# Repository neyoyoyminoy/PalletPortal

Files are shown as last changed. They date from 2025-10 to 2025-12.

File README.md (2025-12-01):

# palletPortal

Pallet Portal is a dual archway automated pallet scanning system designed to streamline outbound shipping operations by integrating barcode detection, object tracking, and manifest verification. It uses the **NVIDIA Jetson Orin Nano**, custom 3D printed hardware, and a Python graphical user interface.

## Overview
- Dual IMX219 cameras for live barcode capture and object tracking.  
- Integrated IR barcode scanner for redundancy and precision.  
- Ultrasonic ping sensors for pallet presence detection and GUI activation.  
- Custom PyQt GUI for real time feedback, mode selection, and system status.  
- Fully 3D printed button interface and display housing, mounted on a dual arch frame.

## Features
- Live dual camera video feed via GStreamer pipeline.  
- Barcode detection and comparison using Pillow/pyzbar/ZXing.  
- Ultrasonic sensor input synchronized with GUI states to prevent crosstalk.  
- Automatic USB manifest detection and reading.  
- Hardware input mapped to GUI navigation (down, cancel, select, up).  
- Custom layered button icons designed in Fusion for tactile control.  

## Hardware
- Jetson Orin Nano Developer Kit  
- Dual IMX219 Cameras  
- Ultrasonic Ping Sensors (HC-SR04)  
- IR Barcode Scanner  
- 3D Printed Components: Display enclosure, button case, dual layer buttons, scaled pallet model (203 mm width)

## Software Stack
| Component | Description |
|---|---|
| Python 3 | Main control and GUI logic |
| PyQt5/Pillow | GUI display and image processing |
| GStreamer | Real time camera pipeline |
| pyzbar/ZXing | Barcode decoding (OpenCV free alternatives) |
| GPIO/Jetson.GPIO | Peripheral communication |
| Threading | Dual camera and sensor concurrency management |

## Current Focus
- Refining UI housing and crossmember mounting.  
- Fusing YOLO individuality to Pillow supportive lightweight detection.  
- Optimizing IR scanner and camera coordination to prevent redundant reads.  
- Improving print efficiency for long 3D jobs (>10 hours per iteration).  

## Known Issues
- Occasional PyQt layout and event conflicts.  
- Camera sensor ID mismatches between CAM0 and CAM1.  
- nvargus daemon instability under high load capture.  
- Jetson thermal throttling during extended use.  
- 3D print size limitations requiring segmented builds.  

## Setup Instructions
```bash
git clone https://github.com/neyoyoyminoy/PalletPortal.git
cd PalletPortal

sudo apt install python3-pyqt5 gstreamer1.0-tools
pip install pillow pyzbar jetson-gpio

python3 GUIv12.py

#this is an optional single camera test; make sure to see current header pin configuration; there can only be sensor 1 and 2 from the 22 header pins
gst-launch-1.0 nvarguscamerasrc sensor-id=0 ! 'video/x-raw(memory:NVMM),width=1280,height=720,framerate=30/1' ! nvvidconv ! videoconvert ! xvimagesink
```

## Contributors
- **Brendan Nellis** — Lead Developer, Hardware Integration, GUI and System Design
- **Simeon-Paul O'James** — Lead AI Model Developer
- **Jose Escareno II** — Lead Hardware Engineer
- **Elliot Cid** — Power Engineer
- **Jim Yanney** — Hardware and Software Implementation Engineer

## License
This project is for academic and research purposes under UTSA Senior Design Fall 2025.  
All code and designs are open for non-commercial educational use.

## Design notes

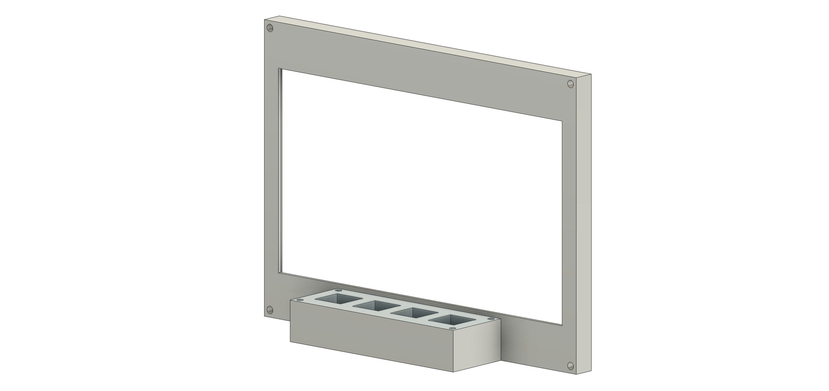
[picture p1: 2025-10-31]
uiCasing/UIv1.png

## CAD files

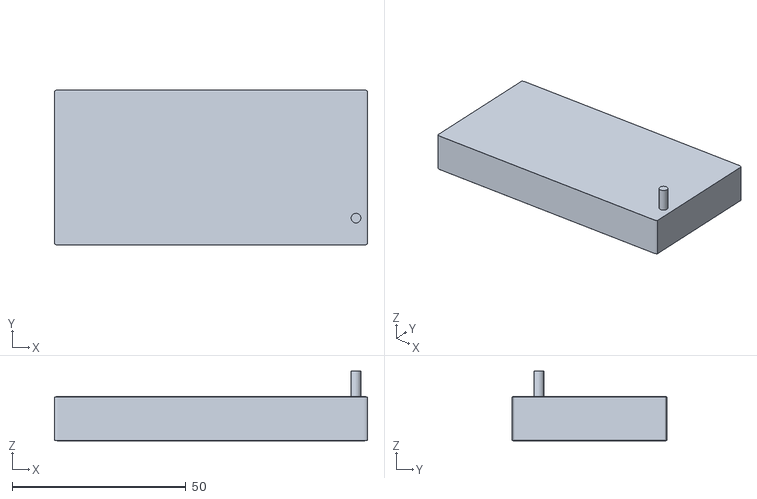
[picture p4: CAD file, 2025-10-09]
3Dprinting/buttonCase/buttonCaseTop.stl
90.0 x 44.7 x 20.0

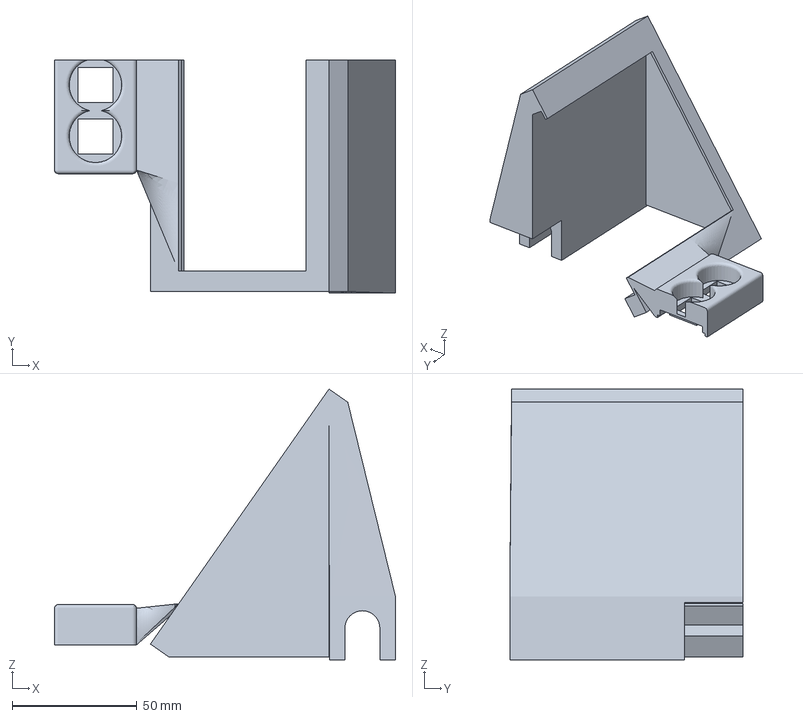
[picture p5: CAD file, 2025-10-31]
uiCasing/UIv2part3.3mf
136.5 x 93.4 x 108.4 mm

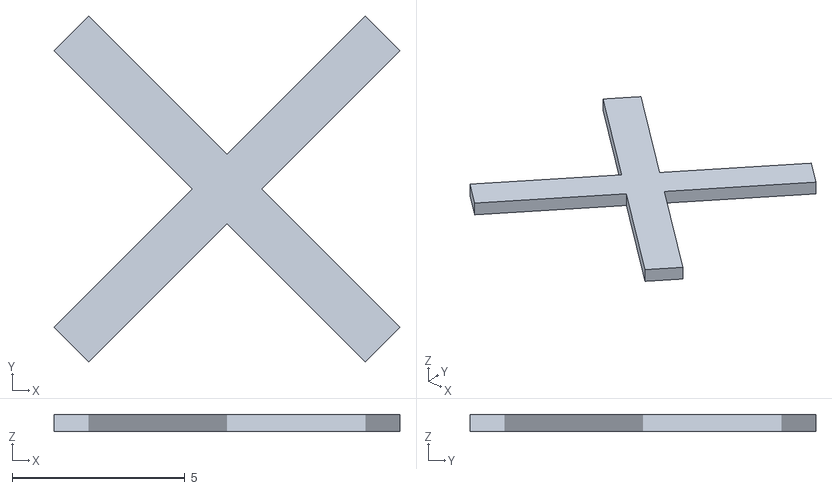
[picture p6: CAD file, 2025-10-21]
3Dprinting/xIcon.stl
10.0 x 10.0 x 0.5

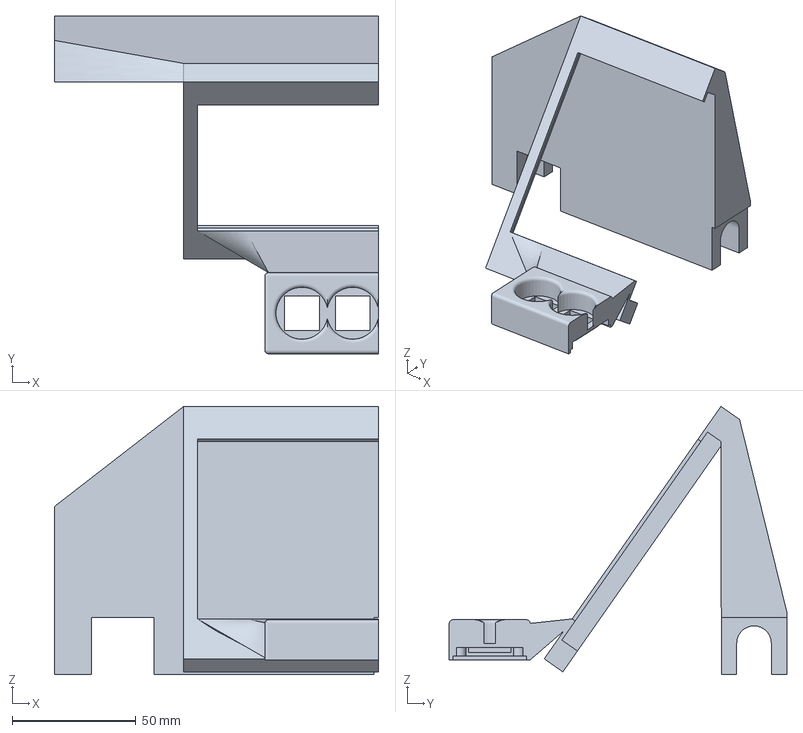
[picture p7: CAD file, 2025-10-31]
uiCasing/UIv2part2.3mf
131.0 x 136.5 x 108.4 mm

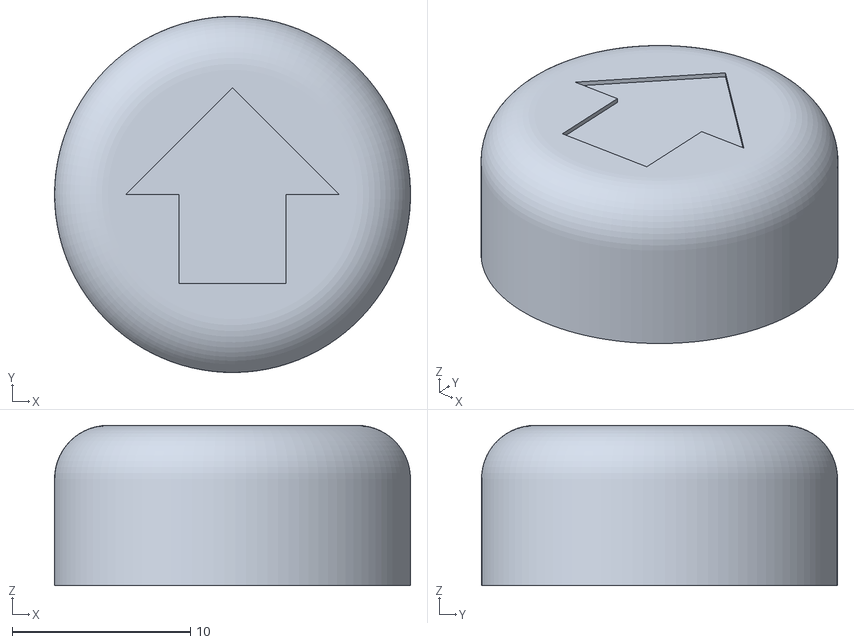
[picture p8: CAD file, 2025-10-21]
3Dprinting/upButtonCap.stl
20.0 x 20.0 x 9.00

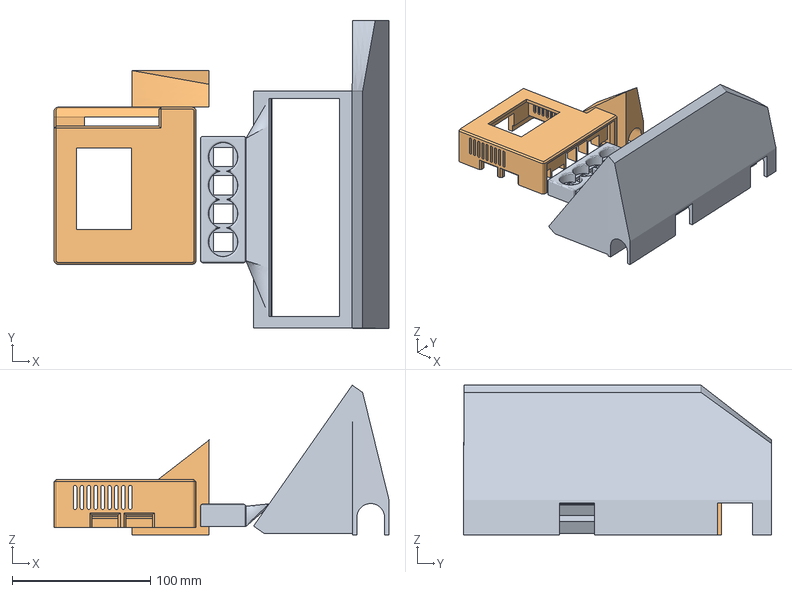
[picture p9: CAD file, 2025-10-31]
uiCasing/UIv3.3mf
242.7 x 223.5 x 108.4 mm
UIv3.stl_A
UIv3.stl_B

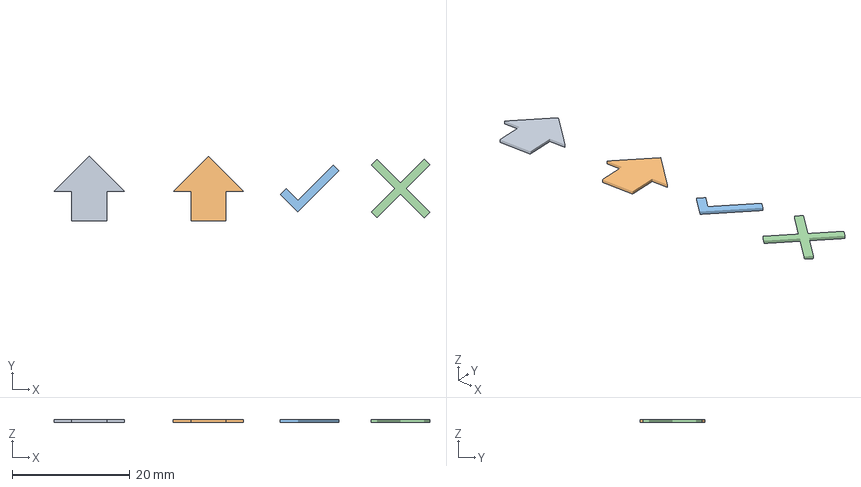
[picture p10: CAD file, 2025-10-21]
3Dprinting/arrowIcon.3mf
64.0 x 11.0 x 0.5 mm
arrowIcon.stl x 2
selIcon.stl
xIcon.stl

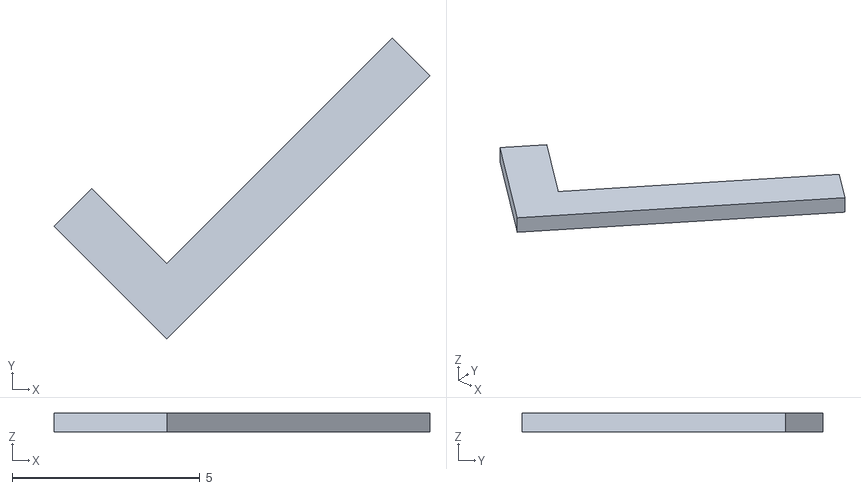
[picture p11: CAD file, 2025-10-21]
3Dprinting/selIcon.stl
10.0 x 8.00 x 0.5

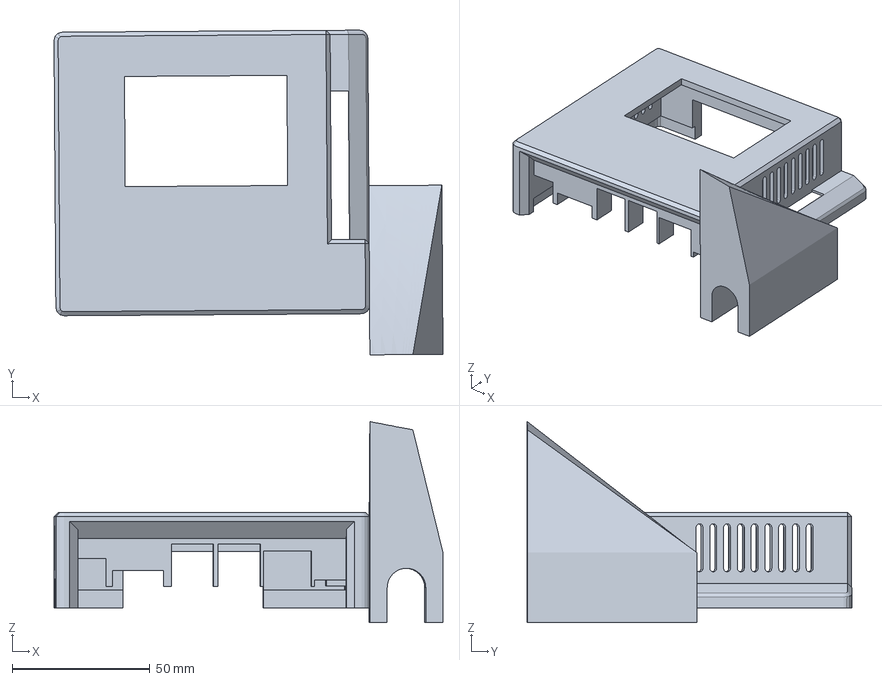
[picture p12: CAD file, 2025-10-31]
uiCasing/UIv2JetsonCasing.3mf
141.3 x 117.9 x 73.0 mm

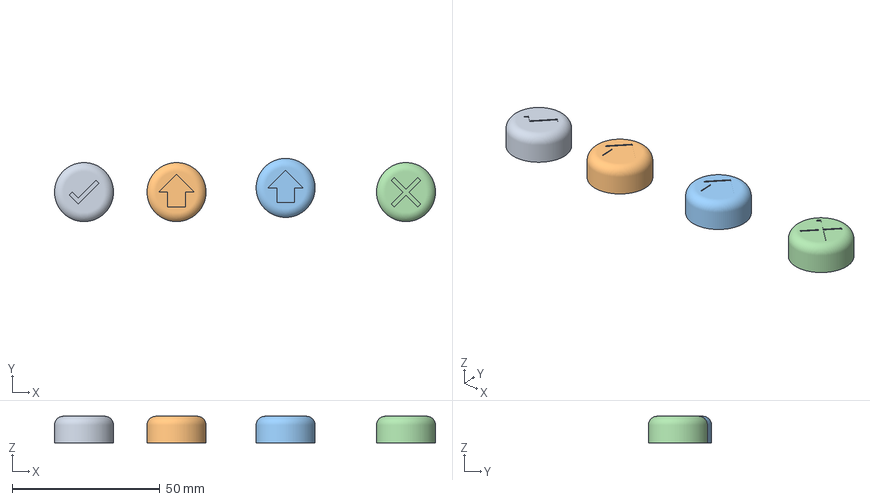
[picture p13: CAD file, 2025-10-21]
3Dprinting/selButtonCap.3mf
129.1 x 21.4 x 9.00 mm
selButtonCap.stl
upButtonCap.stl x 2
xbuttonCap.stl

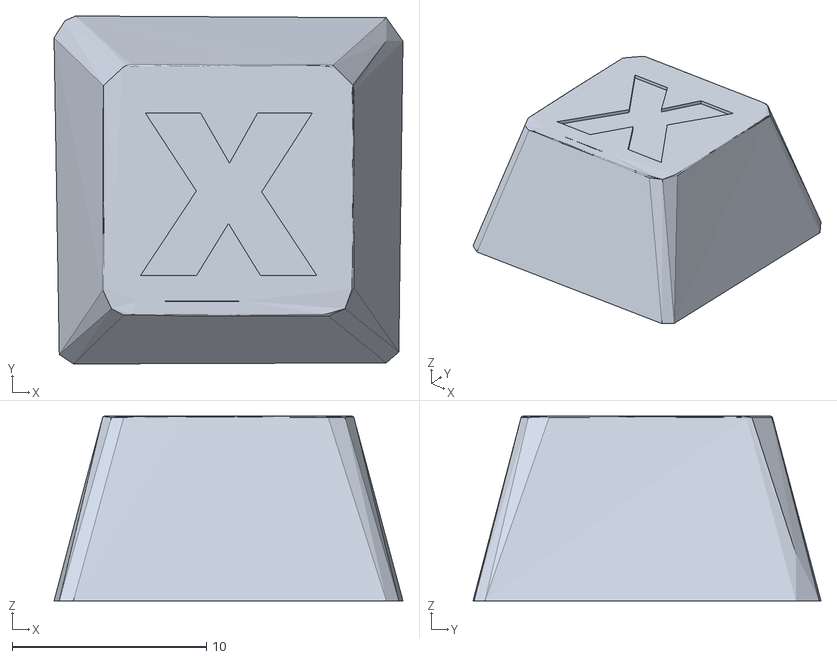
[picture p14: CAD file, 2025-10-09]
3Dprinting/xKey.stl
18.0 x 17.9 x 9.50

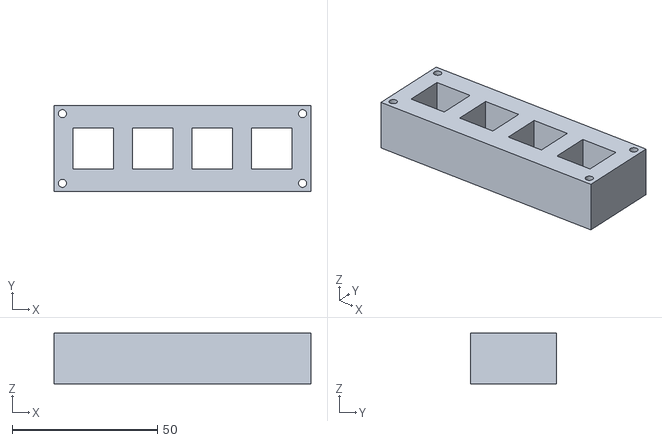
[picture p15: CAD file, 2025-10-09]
3Dprinting/buttonHousingv1.stl
88.6 x 29.8 x 17.5

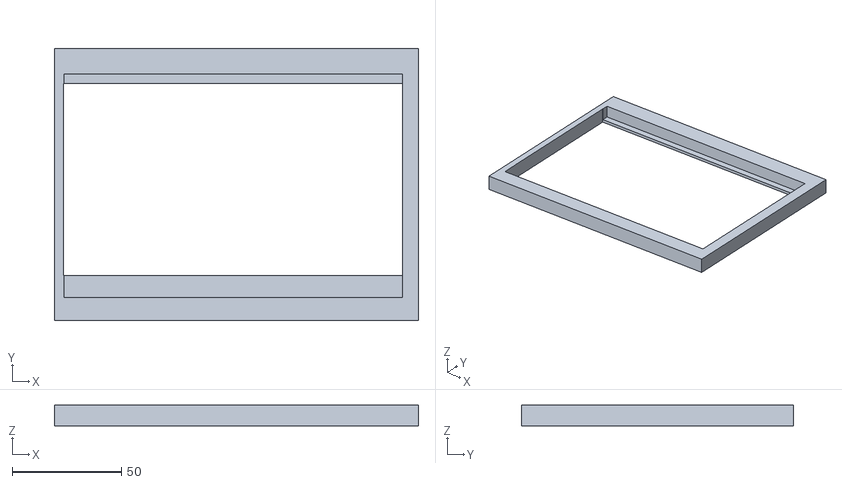
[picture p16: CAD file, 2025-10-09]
3Dprinting/displayCasev3.stl
166.5 x 124.6 x 9.40

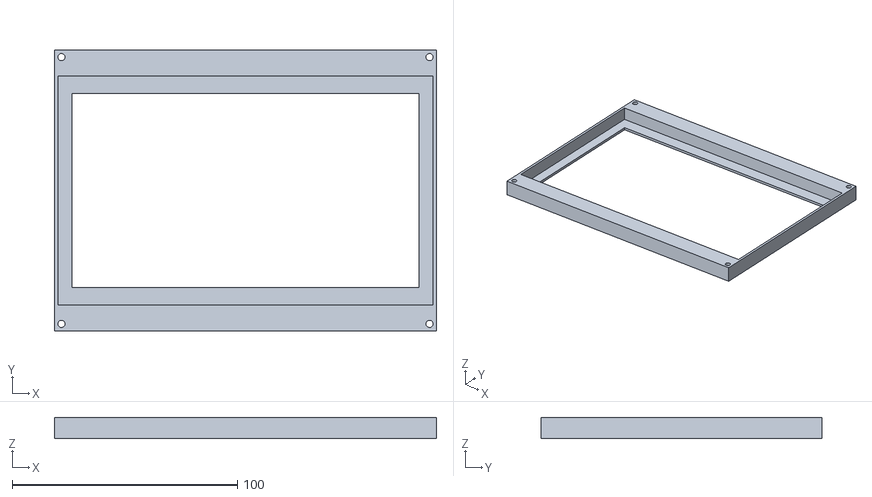
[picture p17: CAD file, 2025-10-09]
3Dprinting/displayCasev2.stl
169.5 x 124.6 x 9.40

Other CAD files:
3Dprinting/buttonCapv3.stl
uiCasing/UIv2.3mf
3Dprinting/xbuttonCap.stl
3Dprinting/selKey.stl
3Dprinting/arrowIcon.stl
3Dprinting/buttonCapv2.stl
3Dprinting/buttonCapv4.stl
3Dprinting/buttonCapv5.stl
3Dprinting/buttonHousingv2.stl
3Dprinting/selButtonCap.stl
uiCasing/UIv2.stl
uiCasing/UIv3.f3z
uiCasing/UIv3.stl

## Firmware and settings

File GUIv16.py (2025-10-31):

'''
this version is built on v15 to implement the Pillow barcode detection and pyzbar decoding from Simeon's code(s)
'''

import os
import re
import sys
import time
from pathlib import Path
from dataclasses import dataclass
from typing import List, Optional, Tuple

from PyQt5.QtCore import Qt, QTimer, pyqtSignal, QObject, QThread
from PyQt5.QtGui import QFont
from PyQt5.QtWidgets import (
    QApplication, QWidget, QLabel, QVBoxLayout, QStackedWidget, QTextEdit
)

#---GPIO for the Jetson Orin Nano---
try:
    import Jetson.GPIO as GPIO #from nvidia jetson gpio docs
    GPIO_AVAILABLE = True
except Exception:
    GPIO_AVAILABLE = False

BARCODE_FILENAME_CANDIDATES = ["barcodes.txt"] #this looks for the manifest text file on the flashdrive
REQUIRED_COUNT = 10 #this was just for testing count detection
REQUIRED_LENGTH = 10 #helps avoid auto reads that arent real barcodes

def guess_mount_roots():
    roots = set()
    user = os.environ.get("USER") or os.environ.get("LOGNAME") or ""
    for base in ["/media", "/mnt", "/run/media"]:
        roots.add(base)
        if user:
            roots.add(os.path.join(base, user))
    roots.add("/media/jetson")
    try:
        with open("/proc/mounts", "r", encoding="utf-8", errors="ignore") as f:
            for line in f:
                parts = line.split()
                if len(parts) >= 3:
                    mnt = parts[1]
                    fstype = parts[2].lower()
                    if any(fs in fstype for fs in ("vfat", "exfat", "ntfs", "fuseblk")):
                        roots.add(mnt)
    except Exception:
        pass
    return [r for r in sorted(roots) if os.path.exists(r)]

DEFAULT_MOUNT_ROOTS = guess_mount_roots() #this gets the possible usb mount points

@dataclass
class ShipmentList:
    def __init__(self, barcodes):
        self.barcodes = barcodes

    @staticmethod
    def parse(text: str):
        if text and text[0] == "\ufeff":
            text = text[1:]

        tokens = re.findall(r"(?<!\d)\d{10}(?!\d)", text) #based on stackoverflow regex for grabbing 10-digit barcodes

        seen = set()
        unique_tokens = []
        for t in tokens:
            if t not in seen:
                seen.add(t)
                unique_tokens.append(t)

        return ShipmentList(unique_tokens) if len(unique_tokens) == 10 else None


class USBWatcher(QObject):
    validListFound = pyqtSignal(ShipmentList, str)
    status = pyqtSignal(str)

    def __init__(self, mount_roots=None, filename_candidates=None, poll_ms=1000, parent=None):
        super().__init__(parent)
        self.mount_roots = mount_roots or DEFAULT_MOUNT_ROOTS
        self.filename_candidates = [c.lower() for c in (filename_candidates or BARCODE_FILENAME_CANDIDATES)] #this looks for the manifest text file on the flashdrive
        self.timer = QTimer(self)
        self.timer.setInterval(poll_ms)
        self.timer.timeout.connect(self.scan_once)

    def start(self):
        self.scan_once()
        self.timer.start()

    def stop(self):
        self.timer.stop()

    def scan_once(self):
        for root in self.mount_roots:
            if not os.path.exists(root):
                continue
            for dirpath, dirnames, filenames in os.walk(root):
                depth = dirpath.strip(os.sep).count(os.sep) - root.strip(os.sep).count(os.sep)
                if depth > 2:
                    dirnames[:] = []
                    continue
                if any(p in dirpath for p in ("/proc", "/sys", "/dev", "/run/lock")):
                    continue
                lower_files = {fn.lower(): fn for fn in filenames}
                for cand_lower in self.filename_candidates:
                    if cand_lower in lower_files:
                        found_name = lower_files[cand_lower]
                        full = os.path.join(dirpath, found_name)
                        try:
                            text = Path(full).read_text(encoding="utf-8", errors="ignore")
                        except Exception as e:
                            self.status.emit(f"Found {found_name} at {dirpath}, but couldn't read it: {e}")
                            continue
                        parsed = ShipmentList.parse(text)
                        if parsed:
                            self.status.emit(f"Valid list found at: {full}")
                            self.validListFound.emit(parsed, dirpath)
                            return
                        else:
                            self.status.emit(f"{found_name} at {dirpath} did not contain exactly {REQUIRED_COUNT} unique {REQUIRED_LENGTH}-digit barcodes.") #this was just for testing count detection
        self.status.emit("Scanning for USB + barcodes file...")

# --------------------Welcome & Menu Screens--------------------
class WelcomeScreen(QWidget):
    proceed = pyqtSignal(ShipmentList, str)

    def __init__(self):
        super().__init__()
        layout = QVBoxLayout(self)

        title = QLabel("Welcome")
        title.setAlignment(Qt.AlignCenter)
        title.setFont(QFont("Beausite Classic", 40))
        title.setStyleSheet("color: #0c2340; background-color: #f15a22; font-weight: bold;")
        layout.addWidget(title)

        subtitle = QLabel("Insert flash drive with barcodes file to begin")
        subtitle.setAlignment(Qt.AlignCenter)
        subtitle.setWordWrap(True)
        layout.addWidget(subtitle)

        self.status = QLabel("Waiting for USB...")
        self.status.setAlignment(Qt.AlignCenter)
        layout.addWidget(self.status)

        self.debug = QTextEdit()
        self.debug.setReadOnly(True)
        self.debug.setVisible(True)
        layout.addWidget(self.debug)

        hint = QLabel("Press 'R' to force a rescan. Looking under: " + ", ".join(DEFAULT_MOUNT_ROOTS))
        hint.setWordWrap(True)
        hint.setAlignment(Qt.AlignCenter)
        layout.addWidget(hint)

        self.watcher = USBWatcher() #creates the usb monitor for barcodes
        self.watcher.status.connect(self._on_status)
        self.watcher.validListFound.connect(self._on_valid)
        self.watcher.start() #starts watching for usb insert

    def keyPressEvent(self, event):
        if event.key() == Qt.Key_R: #press r to manually rescan usb
            self._on_status("Manual rescan requested.")
            self.watcher.scan_once()
            event.accept()
            return
        super().keyPressEvent(event)

    def _on_status(self, msg: str):
        self.status.setText(msg)
        self.debug.append(msg)

    def _on_valid(self, shipment, root):
        self.watcher.stop()
        self.proceed.emit(shipment, root)


class MenuScreen(QWidget): #handles the menu input and navigation
    shipSelected = pyqtSignal()
    viewOrderSelected = pyqtSignal()

    def __init__(self):
        super().__init__()
        self.setFocusPolicy(Qt.StrongFocus)
        self.options = ["Ship", "View Order"]
        self.index = 0

        self.layout = QVBoxLayout(self)
        self.title = QLabel("Menu")
        self.title.setAlignment(Qt.AlignCenter)
        self.title.setFont(QFont("Beausite Classic", 36))
        self.title.setStyleSheet("color: #0c2340; background-color: #f15a22; font-weight: bold;")
        self.layout.addWidget(self.title)

        self.top = QLabel(self.options[0])
        self.bottom = QLabel(self.options[1])
        for lbl in (self.top, self.bottom):
            lbl.setAlignment(Qt.AlignCenter)
            lbl.setFont(QFont("Beausite Classic", 32))
            lbl.setMargin(12)
        self.layout.addWidget(self.top)
        self.layout.addWidget(self.bottom)

        self._refresh()

    def _refresh(self):
        selected_style = "border: 4px solid #0c2340; border-radius: 16px;"
        normal_style = "border: none;"
        self.top.setStyleSheet(selected_style if self.index == 0 else normal_style)
        self.bottom.setStyleSheet(selected_style if self.index == 1 else normal_style)

    def keyPressEvent(self, event):
        key = event.key()
        if key in (Qt.Key_Return, Qt.Key_Enter):
            self.index = (self.index - 1) % 2
            self._refresh()
            event.accept()
            return
        if key == Qt.Key_Control:
            self.index = (self.index + 1) % 2
            self._refresh()
            event.accept()
            return
        if key == Qt.Key_V:
            if self.index == 0:
                self.shipSelected.emit()
            else:
                self.viewOrderSelected.emit()
            event.accept()
            return
        super().keyPressEvent(event)

# --------------------ship screen with ping sensor wait--------------------
PING_PINS_BOARD = [15, 32]
DETECTION_THRESHOLD_IN = 18
MB1040_US_PER_INCH = 147.0


class PingWorker(QThread): #thread that reads ping sensors without crosstalk
    """
    Crosstalk-safe ultrasonic polling thread.
    - Alternates sensors with long settle time between switching (like jetson_ping_crosstalk).
    - Adds a short quiet period after each read.
    - Averages multiple pulse-width samples, trimming outliers.
    - Emits ready(distance_inches, pin_used) ONLY when distance <= DETECTION_THRESHOLD_IN.
    - Never returns after first reading; loops until stopped.
    """
    ready = pyqtSignal(float, int)
    log = pyqtSignal(str)

    def __init__(self, pins_board: List[int]):
        super().__init__()
        self.pins = [p for p in pins_board if p is not None]
        self._stop = False

        self.settle_time_s = 3.0
        self.quiet_time_s = 0.5
        self.samples = 7

    def stop(self):
        self._stop = True

    def run(self):
        if not GPIO_AVAILABLE:
            self.log.emit("GPIO not available; simulating sensor after 1s.")
            time.sleep(1.0)
            self._emit_log_and_maybe_ready(24.0, -1)
            return

        try:
            GPIO.setmode(GPIO.BOARD) #standard jetson gpio pin mode setup
            for p in self.pins:
                GPIO.setup(p, GPIO.IN)

            self.log.emit(f"Starting ping initialization with crosstalk-safe alternation on pins (BOARD): {self.pins}")
            last_pin = None
            while not self._stop:
                for pin in self.pins:
                    if self._stop:
                        break

                    if last_pin is None or pin != last_pin:
                        self.log.emit(f"Reading sensor on pin {pin} (settle {self.settle_time_s:.1f}s)...")
                        self._sleep(self.settle_time_s)
                    else:
                        self.log.emit(f"Reading sensor on pin {pin}...")

                    dist_in = self._read_distance_in(pin, samples=self.samples)

                    if dist_in is not None:
                        self.log.emit(f"Pin {pin}: {dist_in:.2f} in")
                        self._emit_log_and_maybe_ready(dist_in, pin)
                    else:
                        self.log.emit(f"Pin {pin}: no valid reading (timeout / noise).")

                    last_pin = pin
                    self._sleep(self.quiet_time_s)

        except Exception as e:
            self.log.emit(f"PingWorker error: {e!r}")
        finally:
            self._cleanup()

    def _emit_log_and_maybe_ready(self, dist_in: float, pin: int):
        try:
            threshold = DETECTION_THRESHOLD_IN
        except NameError:
            threshold = 18
        if dist_in <= threshold:
            self.ready.emit(dist_in, pin) #sends signal when distance is under threshold

    def _sleep(self, seconds: float):
        end = time.time() + seconds
        while not self._stop and time.time() < end:
            time.sleep(0.01) #tiny delay to smooth readings

    def _cleanup(self):
        if GPIO_AVAILABLE:
            try:
                GPIO.cleanup() #cleanup per jetson gpio best practice
            except Exception:
                pass

    # --- Low-level pulse width sampling ---
    def _measure_pw_us(self, pin: int, timeout_s: float = 0.06) -> Optional[float]:
        """
        Measure the pulse width (in microseconds) of one MB1040 echo.
        Returns None on timeout.
        """
        start = time.time()
        while GPIO.input(pin) == GPIO.HIGH:
            if self._stop or (time.time() - start) > timeout_s:
                return None
        while GPIO.input(pin) == GPIO.LOW:
            if self._stop or (time.time() - start) > timeout_s:
                return None
        rise = time.perf_counter()
        while GPIO.input(pin) == GPIO.HIGH:
            if self._stop or (time.time() - start) > timeout_s:
                return None
        fall = time.perf_counter()
        return (fall - rise) * 1e6 #convert echo pulse to microseconds

    def _read_distance_in(self, pin: int, samples: int = 7) -> Optional[float]:
        pws = []
        for _ in range(samples):
            if self._stop:
                return None
            pw = self._measure_pw_us(pin)
            if pw is None:
                continue
            dist_in = pw / MB1040_US_PER_INCH
            if 1.0 <= dist_in <= 300.0:
                pws.append(dist_in)
            time.sleep(0.01) #tiny delay to smooth readings

        if not pws:
            return None

        pws.sort()
        if len(pws) >= 5:
            pws = pws[1:-1]
        return sum(pws) / len(pws)


class ShipScreen(QWidget):
    def __init__(self):
        super().__init__()
        layout = QVBoxLayout(self)
        title = QLabel("Ship")
        title.setAlignment(Qt.AlignCenter)
        title.setFont(QFont("Beausite Classic", 36))
        title.setStyleSheet("color: #0c2340; background-color: #f15a22; font-weight: bold;")
        layout.addWidget(title)

        self.status = QLabel("Waiting for ping sensor...")
        self.status.setAlignment(Qt.AlignCenter)
        layout.addWidget(self.status)

        self.log = QTextEdit()
        self.log.setReadOnly(True)
        self.log.setVisible(True) #keep visible per user
        layout.addWidget(self.log)

        self._expected_codes = [] #this will hold the manifest barcodes from usb
        self._barcode_worker = None #this gets created after ping ready

        pins = list(PING_PINS_BOARD)
        if OPTIONAL_SECOND_PIN is not None:
            pins.append(OPTIONAL_SECOND_PIN)
        self.worker = PingWorker(pins)
        self.worker.log.connect(self._log)
        self.worker.ready.connect(self._on_ready)
        self.worker.start()

    def set_manifest_codes(self, codes):
        #this gets called by mainwindow after usb watcher succeeds
        self._expected_codes = list(codes or [])

    def _log(self, msg: str):
        self.log.append(msg)

    def _on_ready(self, dist_in: float, pin: int):
        self.status.setText("CSI cameras are starting...") #starts camera after ping ready
        self._log(f"ready from pin {pin}, distance ~{dist_in:.2f} in")
        if self._barcode_worker is None:
            self._barcode_worker = BarcodeReaderWorker(
                model_path="my_model.pt",
                sensor_id=0,
                width=1280, height=720, framerate=30,
                min_conf=0.25, iou=0.45, max_rois=6,
                decode_every=1, fallback_interval=15,
                manifest_codes=self._expected_codes
            )
            self._barcode_worker.log.connect(self._log)
            self._barcode_worker.finished_all.connect(self._on_all_done)
            self._barcode_worker.start()

    def _on_all_done(self):
        self.status.setText("all barcodes found — scanning complete")
        try:
            if self.worker.isRunning():
                self.worker.stop()
        except Exception:
            pass

    def closeEvent(self, e):
        try:
            if self.worker.isRunning():
                self.worker.stop()
                self.worker.wait(500)
        except Exception:
            pass
        try:
            if self._barcode_worker and self._barcode_worker.isRunning():
                self._barcode_worker.stop()
                self._barcode_worker.wait(800)
        except Exception:
            pass
        super().closeEvent(e)

class ViewOrderScreen(QWidget):
    def __init__(self):
        super().__init__()
        layout = QVBoxLayout(self)
        title = QLabel("View Order")
        title.setAlignment(Qt.AlignCenter)
        title.setFont(QFont("Beausite Classic", 36))
        title.setStyleSheet("color: #0c2340; background-color: #f15a22; font-weight: bold;")
        layout.addWidget(title)

# --------------------Main window--------------------

# --------------------embedded: simple manifest matcher--------------------
#this wraps the usb-loaded barcodes into a simple matcher for exact checks
#based on manifest_matcher.py ideas (load and case-insensitive lookup)
class SimpleManifestMatcher:
    #this keeps a set and a dict for quick exact matches
    def __init__(self, codes):
        self.codes = [str(c).strip() for c in (codes or []) if str(c).strip()]
        self._lut = {c.lower(): c for c in self.codes}  #lower for lookup, keep original for echo #based on manifest_matcher.py lookup map
    def match(self, code: str):
        if not code:
            return None, 0, "none"
        key = str(code).strip().lower()
        if key in self._lut:
            return self._lut[key], 100, "exact"  #exact match like teammate script prints #based on manifest_matcher.py match()
        return None, 0, "none"

# --------------------embedded: CSI camera barcode reader worker--------------------
#this uses pillow + yolo + pyzbar + gstreamer to read barcodes from the csi cam
#based on yolo_pillow_manifest.py functions and loop
from PyQt5.QtCore import pyqtSignal, QThread
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

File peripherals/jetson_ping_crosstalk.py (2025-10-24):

"""
Dual MB1040 Ultrasonic Sensor Test – jetson orin nano
this code has been adapted from the crosstalk_filteringv2.
"""

import Jetson.GPIO as GPIO
import time
import statistics

# --- Pin assignments (BOARD numbering) ---
# for jetson we need 
SENSOR1_PIN = 15
SENSOR2_PIN = 32

GPIO.setmode(GPIO.BOARD)
GPIO.setup(SENSOR1_PIN, GPIO.IN)
GPIO.setup(SENSOR2_PIN, GPIO.IN)

# --- Sensor limits ---
HARD_MIN_IN = 6.0    # below this = impossible
SOFT_MIN_IN = 13.0   # below this, smooth to last valid
MAX_IN = 254.0       # max reliable distance

# Keep track of last valid reading for smoothing
last_valid = {SENSOR1_PIN: None, SENSOR2_PIN: None}

def measure_pulse(pin):
    """Measure one PWM pulse width (µs) on the given GPIO pin."""
    GPIO.wait_for_edge(pin, GPIO.RISING)
    start = time.monotonic_ns()
    GPIO.wait_for_edge(pin, GPIO.FALLING)
    end = time.monotonic_ns()
    return (end - start) / 1000.0  # µs

def read_distance(pin, label, samples=5):
    """Read several pulses, average valid results, print distance."""
    global last_valid
    distances = []
    for _ in range(samples):
        width_us = measure_pulse(pin)
        distance_in = width_us / 147.0  # per datasheet
        if HARD_MIN_IN <= distance_in <= MAX_IN:
            distances.append(distance_in)
        time.sleep(0.05)  # small gap between samples

    if distances:
        avg_in = statistics.mean(distances)

        # Apply soft lower limit smoothing
        if avg_in < SOFT_MIN_IN:
            if last_valid[pin] is not None:
                # Smooth: average with last valid
                avg_in = (avg_in + last_valid[pin]) / 2.0
            # else: no last value, use as-is (might be slightly unstable)

        last_valid[pin] = avg_in
        avg_cm = avg_in * 2.54
        print(f"{label} → {avg_in:.2f} in ({avg_cm:.2f} cm)")

    elif last_valid[pin] is not None:
        # Reuse last valid reading
        avg_in = last_valid[pin]
        avg_cm = avg_in * 2.54
        print(f"{label} → Using last valid reading ({avg_in:.2f} in / {avg_cm:.2f} cm)")

    else:
        print(f"{label} → Out of range")

try:
    print("Alternating MB1040 readings every 3 s with soft lower limit smoothing...")
    while True:
        # --- Sensor 1 ---
        read_distance(SENSOR1_PIN, "Sensor 1")
        time.sleep(0.5)   # quiet time before switching

        # --- Wait 3 s before Sensor 2 ---
        time.sleep(3.0)

        # --- Sensor 2 ---
        read_distance(SENSOR2_PIN, "Sensor 2")
        time.sleep(0.5)

        # --- Wait 3 s before switching back ---
        time.sleep(3.0)

except KeyboardInterrupt:
    print("\nExiting...")

finally:
    GPIO.cleanup()

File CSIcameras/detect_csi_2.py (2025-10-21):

import os
import sys
import argparse
import glob
import time

import cv2
import numpy as np
from ultralytics import YOLO


def gstreamer_pipeline(
    sensor_id=1,
    capture_width=1640,
    capture_height=1232,
    display_width=1280,
    display_height=720,
    framerate=30,
    flip_method=2,
):
    """Build a Jetson CSI camera pipeline string for OpenCV (GStreamer)."""
    return (
        "nvarguscamerasrc sensor-id=%d ! "
        "video/x-raw(memory:NVMM), width=(int)%d, height=(int)%d, "
        "format=(string)NV12, framerate=(fraction)%d/1 ! "
        "nvvidconv flip-method=%d ! "
        "video/x-raw, width=(int)%d, height=(int)%d, format=(string)BGRx ! "
        "videoconvert ! video/x-raw, format=(string)BGR ! appsink"
        % (
            sensor_id,
            capture_width,
            capture_height,
            framerate,
            flip_method,
            display_width,
            display_height,
        )
    )


parser = argparse.ArgumentParser(
    description="YOLO detect: USB/video/images + Jetson CSI via GStreamer"
)
parser.add_argument(
    "--model",
    required=True,
    help='Path to YOLO model file (example: "runs/detect/train/weights/best.pt")',
)
parser.add_argument(
    "--source",
    required=True,
    help=(
        'Image file ("test.jpg"), folder ("imgs/"), video ("vid.mp4"), '
        'USB cam index ("usb0"), Jetson CSI ("csi0"), or Picamera2 ("picamera0").'
    ),
)
parser.add_argument(
    "--thresh",
    type=float,
    default=0.5,
    help='Minimum confidence threshold for drawing boxes (e.g. 0.4).',
)
parser.add_argument(
    "--resolution",
    default=None,
    help='WxH to display/infer at (e.g. "1280x720"). If omitted, uses source/native.',
)
parser.add_argument(
    "--record",
    action="store_true",
    help='Record video/webcam to "demo1.avi" (requires --resolution).',
)
# CSI-only quality controls (optional but handy)
parser.add_argument("--csi-fps", type=int, default=60, help="CSI framerate (default 60).")
parser.add_argument("--csi-flip", type=int, default=0, help="CSI flip-method (0..7; common: 0 or 2).")
parser.add_argument(
    "--csi-sensor",
    type=int,
    default=0,
    help="CSI sensor-id (0 for CAM0, 1 for CAM1 on many Jetson carriers).",
)

args = parser.parse_args()

model_path = args.model
img_source = args.source
min_thresh = float(args.thresh)
user_res = args.resolution
record = args.record

if not os.path.exists(model_path):
    print(
        "ERROR: Model path is invalid or model was not found. Make sure the model filename was entered correctly."
    )
    sys.exit(1)

model = YOLO(model_path, task="detect")
labels = model.names

img_ext_list = [
    ".jpg",
    ".JPG",
    ".jpeg",
    ".JPEG",
    ".png",
    ".PNG",
    ".bmp",
    ".BMP",
]
vid_ext_list = [".avi", ".mov", ".mp4", ".mkv", ".wmv"]

# Classify source type
if os.path.isdir(img_source):
    source_type = "folder"
elif os.path.isfile(img_source):
    _, ext = os.path.splitext(img_source)
    if ext in img_ext_list:
        source_type = "image"
    elif ext in vid_ext_list:
        source_type = "video"
    else:
        print(f"File extension {ext} is not supported.")
        sys.exit(1)
elif img_source.startswith("usb"):
    source_type = "usb"
    usb_idx = int(img_source[3:])
elif img_source.startswith("picamera"):
    source_type = "picamera"
    picam_idx = int(img_source[8:])
elif img_source.startswith("csi"):
    source_type = "csi"
    csi_idx = int(img_source[3:]) if len(img_source) > 3 else 0
else:
    print(f"Input {img_source} is invalid. Please try again.")
    sys.exit(1)

# Resolution handling
resize = False
if user_res:
    try:
        resW, resH = [int(x) for x in user_res.lower().split("x")]
        resize = True
    except Exception:
        print("--resolution must look like 1280x720")
        sys.exit(1)

# Optional recording
if record:
    if source_type not in ["video", "usb", "csi", "picamera"]:
        print("Recording only works for video and camera sources. Please try again.")
        sys.exit(1)
    if not user_res:
        print("Please specify --resolution to record video.")
        sys.exit(1)

    record_name = "demo1.avi"
    record_fps = 30
    recorder = cv2.VideoWriter(
        record_name, cv2.VideoWriter_fourcc(*"MJPG"), record_fps, (resW, resH)
    )

# Open capture per source
if source_type == "image":
    imgs_list = [img_source]
elif source_type == "folder":
    imgs_list = []
    for file in glob.glob(os.path.join(img_source, "*")):
        _, file_ext = os.path.splitext(file)
        if file_ext in img_ext_list:
            imgs_list.append(file)
elif source_type in ("video", "usb"):
    cap_arg = img_source if source_type == "video" else usb_idx
    cap = cv2.VideoCapture(cap_arg)
    if user_res:
        cap.set(cv2.CAP_PROP_FRAME_WIDTH, resW)
        cap.set(cv2.CAP_PROP_FRAME_HEIGHT, resH)
elif source_type == "picamera":
    from picamera2 import Picamera2

    cap = Picamera2()
    if user_res:
        cap.configure(
            cap.create_video_configuration(main={"format": "XRGB8888", "size": (resW, resH)})
        )
    else:
        cap.configure(cap.create_video_configuration(main={"format": "XRGB8888"}))
    cap.start()
elif source_type == "csi":
    # Build GStreamer string for CSI and open with CAP_GSTREAMER
    if not user_res:
        # Use capture/display sizes the same if none is provided
        resW, resH = 1280, 720
    pipeline = gstreamer_pipeline(
        sensor_id=args.csi_sensor if img_source == "csi" else csi_idx,
        capture_width=resW,
        capture_height=resH,
        display_width=resW,
        display_height=resH,
        framerate=args.csi_fps,
        flip_method=args.csi_flip,
    )
    cap = cv2.VideoCapture(pipeline, cv2.CAP_GSTREAMER)
    if not cap.isOpened():
        print("Unable to open CSI camera via GStreamer. Check ribbon seating, camera enable, and nvargus-daemon.")
        sys.exit(1)

bbox_colors = [
    (164, 120, 87),
    (68, 148, 228),
    (93, 97, 209),
    (178, 182, 133),
    (88, 159, 106),
    (96, 202, 231),
    (159, 124, 168),
    (169, 162, 241),
    (98, 118, 150),
    (172, 176, 184),
]

avg_frame_rate = 0.0
frame_rate_buffer = []
fps_avg_len = 200
img_count = 0

window_title = "YOLO detection results"
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

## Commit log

2025-10-08 Add files via upload
    single ping sensor test using jetson orin nano GPIO pins
2025-10-08 Add files via upload
    This iteration uses two ping sensors to print out a statement saying the cameras are ready to use. This will be used in another version where two CSI cameras will wake up from the ping sensors
2025-10-08 Add files via upload
    adding ping sensors for a future camera watchdog
2025-11-10 Add files via upload
    This is Joey's fix on the crosstalk issue with the dual ping sensors having slight interference or incorrect distance measurements. It is built from my GUIv18 script
2025-11-10 Update GUIv20.py
    updated to use the first LED strip with SPI0 on pin 19
2025-11-11 Add files via upload
    this works for our 5 led strip
2025-11-11 Create GUIv21.py
    this fixes the function of the led strip to activate all 5 WS812
2025-11-11 Create GUIv22.py
    added second strip of leds
2025-11-12 Add files via upload
    using two cameras, crude code
2025-11-19 Add files via upload
    GUIv28 with updated logic for vertical barcode scanning with _unwarp_barcode() integrated, _decode_from_rois() modified, optional rotation normalization, logging additions so we can confirm unwarp is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
2025-11-20 Update and rename camera.py to peripherals/camera.py
2025-11-20 Update and rename camera.py to camera.py
